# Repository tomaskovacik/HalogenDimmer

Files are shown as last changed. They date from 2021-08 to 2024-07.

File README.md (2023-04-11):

# HalogenDimmer
HW and SW for running halogen bulbs at 30% to act as daytime running lights.

# Overview
Module supports:
  - fade in at startup
  - fade out at shutdown
  - temporary disable with 3s delay (turn of DRL when turn signal is used, when using diodes more then one source of disable can used (low beams, turn signal... )
  - full on input for high beams, independent of microcontroler, used for light flasher and high beams
  - 30s turn off delay (comming home mode) - require permanent 12v supply and separete switched 12V connection to enable wire 
  
  # how-to connect module in headlight
  
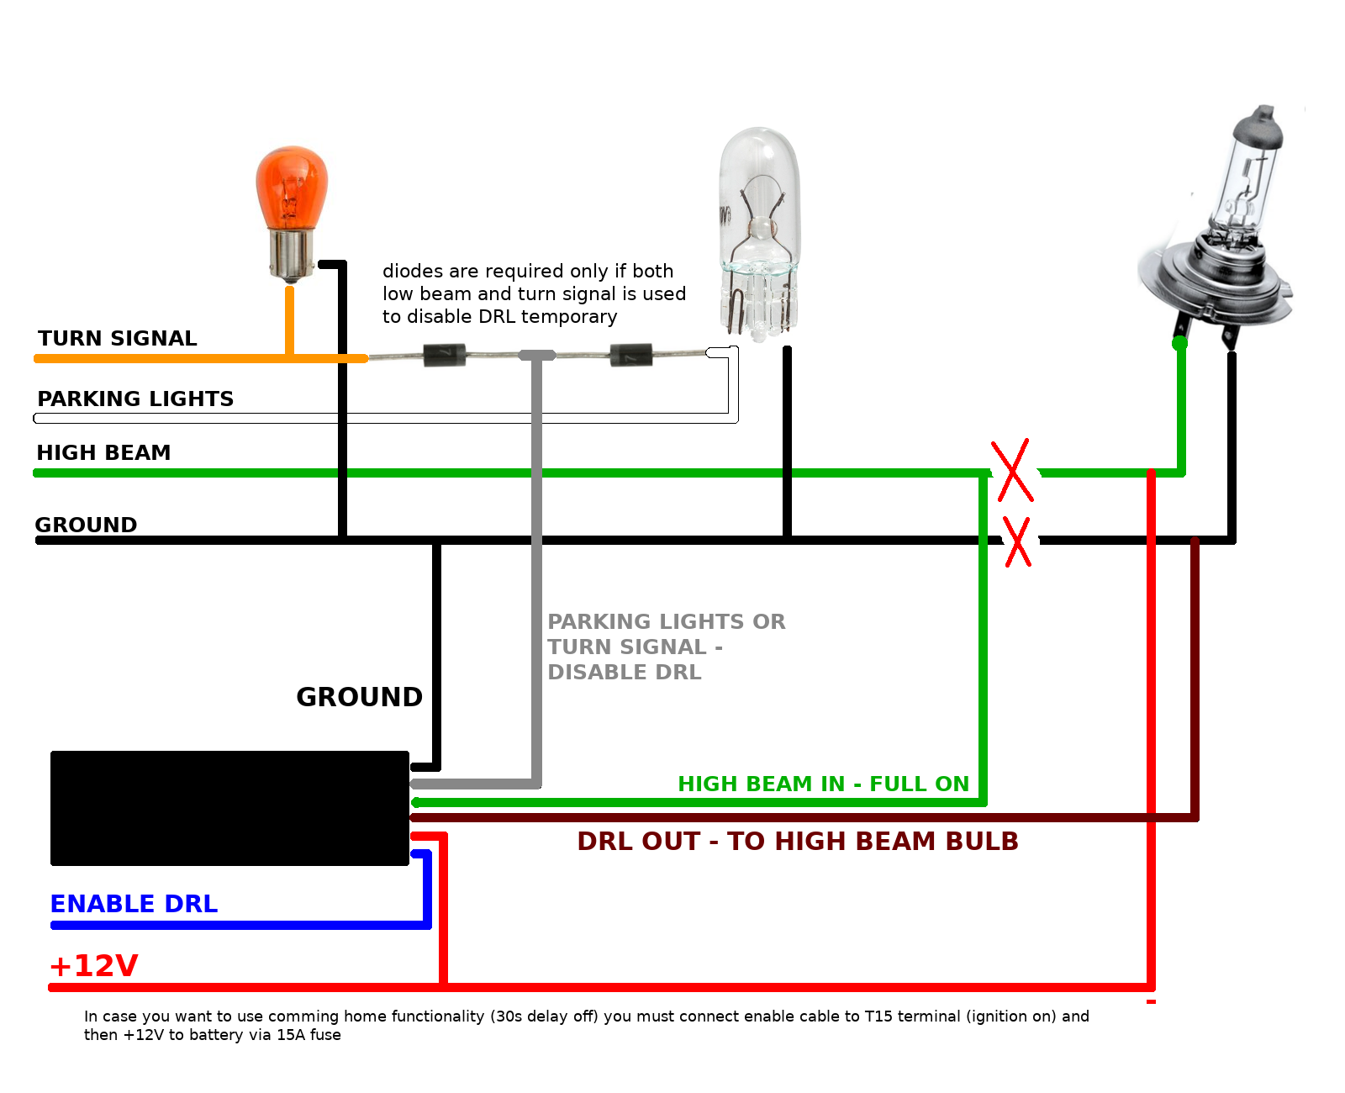
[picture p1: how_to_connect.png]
  
  
  # pinout
  
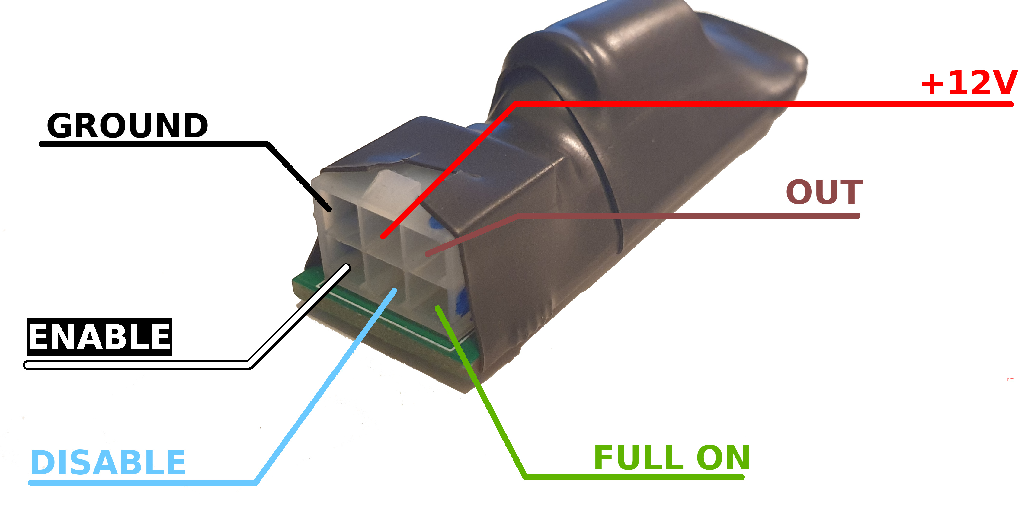
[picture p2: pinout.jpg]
  
  
  # video
  
  https://youtu.be/wNnqLfvapEo

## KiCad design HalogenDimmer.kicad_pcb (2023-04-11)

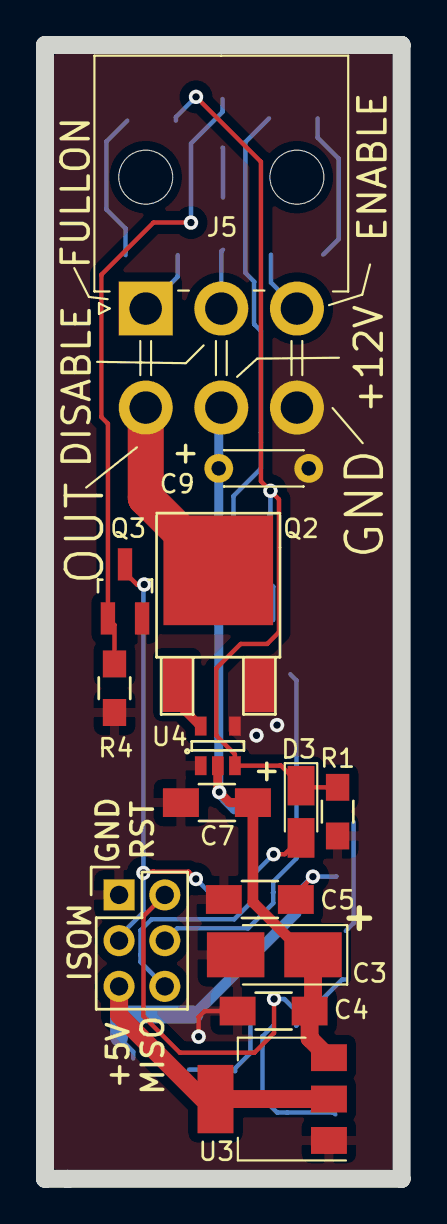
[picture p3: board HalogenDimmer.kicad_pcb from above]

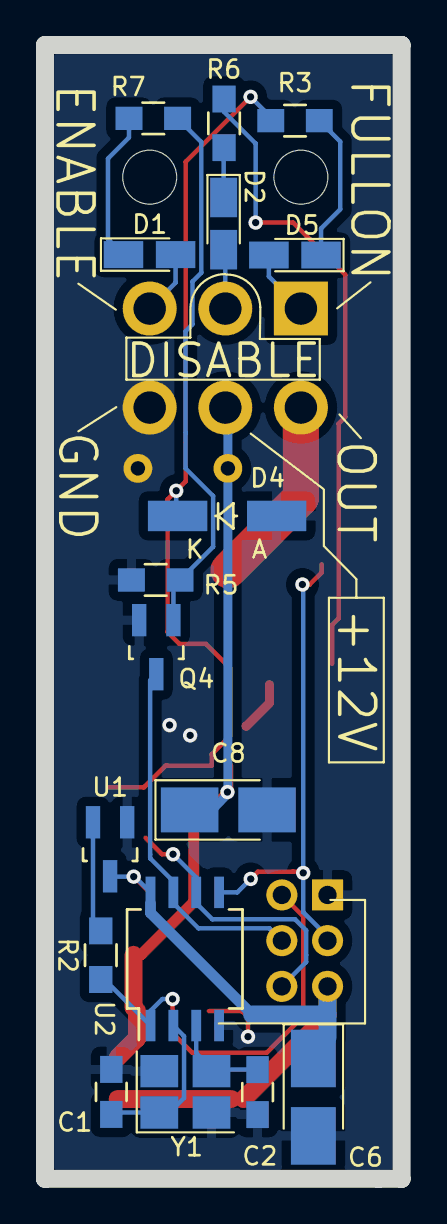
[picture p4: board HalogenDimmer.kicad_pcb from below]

Board: 2 copper layers, 19.8 x 63.0 mm, 31 parts (17 on the bottom side), 21 nets.

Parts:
C1, C2: 22p; C_0805_HandSoldering
C3: 22m/20V; CP_Tantalum_Case-B_EIA-3528-21_Hand
C4, C5, C7: 100n; C_1206_HandSoldering
C6: 47m/10V; CP_Tantalum_Case-B_EIA-3528-21_Hand
C8: 1m/10V; CP_Tantalum_Case-B_EIA-3528-21_Hand
C9: 1000m/16v; C_Disc_D4.3mm_W1.9mm_P5.00mm
D1, D2: NP; D_MicroMELF_Hadsoldering
D3, D5: 1n4148; D_MicroMELF_Hadsoldering
D4: 5V1; MiniMELF_Handsoldering
J1: SPI; Pin_Header_Straight_2x03
J5: INPUT_SIGNALS; Molex_MiniFit-JR-5569-06A2_2x03x4.20mm_Angled
Q2: IRL2905; TO-252-2Lead
Q3, Q4: BC817; SOT-23_Handsoldering
R1, R3, R4, R5: 1k; R_0805_HandSoldering
R2, R6, R7: 10k; R_0805_HandSoldering
U1: MAX809; SOT-23_Handsoldering
U2: ATtiny85-20SU; SO-8_5.3x6.2mm_Pitch1.27mm
U3: NCP1117LPST50T3G; SOT-223-3_TabPin2
U4: MCP1402; SOT-23-5
Y1: Crystal_GND24; Crystal_SMD_3225-4pin_3.2x2.5mm_HandSoldering

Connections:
+5V: C5.1, C6.1, J1.5, U1.3 (VCC), U2.8 (VCC), U3.2 (VO)
+12V: C3.1, C4.1, C7.1, C8.1, C9.1, J5.5, U3.3 (VI), U4.2 (Vdd)
/DISABLE: D2.2 (A), J5.2
/ENABLE: D1.2 (A), J5.3
/FULLON: D5.2 (A), J5.1
/MISO: D3.2 (A), J1.6, U2.6 (PB1)
/MOSI: J1.3, Q3.3 (C), U2.5 (AREF/PB0)
/OUT: J5.4, Q2.2 (D)
/PB2: J1.4, Q4.3 (C), U2.7 (PB2)
/RESET: J1.2, R2.1, U2.1 (~RESET~/PB5)
/XTAL1: C1.1, U2.2 (XTAL1/PB3), Y1.1
/XTAL2: C2.1, U2.3 (XTAL2/PB4), Y1.3
GND: C1.2, C2.2, C3.2, C4.2, C5.2, C6.2, C7.2, C8.2, C9.2, D4.2 (A), J1.1, J5.6, Q2.3 (S), Q3.2 (E), Q4.2 (E), R1.1, R4.2, R5.2, U1.1 (GND), U2.4 (GND), U3.1 (GND), U4.1 (GND), U4.4 (GND), Y1.2, Y1.4
unnamed: D1.1 (K), R7.2
unnamed: D2.1 (K), R6.2
unnamed: D3.1 (K), D4.1 (K), R1.2, R3.1, U4.3 (IN)
unnamed: D5.1 (K), R3.2
unnamed: Q2.1 (G), U4.5 (OUT)
unnamed: Q3.1 (B), R4.1, R6.1
unnamed: Q4.1 (B), R5.1, R7.1
unnamed: R2.2, U1.2 (RESET)

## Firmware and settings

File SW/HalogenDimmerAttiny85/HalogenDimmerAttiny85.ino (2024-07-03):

// (c) kovo
//hallogen dimmer

/*
 * 3.7.2024 kovo: typos, cleanup commented out code 
 */

//timer1 @ 64Mhz
#include <avr/sleep.h>    // Sleep Modes
#include <avr/power.h>    // Power management

#define DELAY 50 // delay used in fade in, used to start DRL
#define DUTY 30 // duty cycle for DRL
#define OUT_PIN 1   //PB1 - output for PWM signal 
#define ONOFF_PIN 2    //PB2 - detecting if ON/OFFF state + wakeup from sleep - must be PB2 because INT0
#define DISABLE_PIN 0   //PB0 - detecting turnsignal, lowbeam etc to disable PWM high beam output
#define TURNSIGNAL_DELAY 5000 //safe delay to enable back DRL's if not turnsignal is present (or lowbeams...)
#define COMMING_HOME_DELAY 30000

enum state {
  OFF, // everything is off
  ON,// DRL ON
  SLEEP, //LOWPOWER MODE
  DISABLE, //LOW BEAMS ON,TURNSIGNAL ON, DRL OFF, NO SLEEP
  COMMING_HOME //30s delay before sleep
};


volatile uint8_t status = OFF;
volatile long disable_start_time;
volatile long offdelay_time;
volatile uint8_t set_duty = 0;

void go2sleep ()
{
  set_duty=0;
  analogWrite(OUT_PIN, set_duty);
  PCMSK  |= bit (PCINT2);  // want pin D4 / pin 3
  GIFR   |= bit (PCIF);    // clear any outstanding interrupts
  GIMSK  |= bit (PCIE);    // enable pin change interrupts
  set_sleep_mode(SLEEP_MODE_PWR_DOWN);
  ADCSRA = 0;            // turn off ADC
  power_all_disable();  // power off ADC, Timer 0 and 1, serial interface
  sleep_enable();
  sleep_cpu();
  sleep_disable();
  power_all_enable();    // power everything back on
  GIMSK  &= ~ (1 << PCIE); // enable pin change interrupts
  status = OFF;
}  // end of goToSleep

void DRL_ON() {
  for (set_duty = 0; set_duty < DUTY; set_duty++) {
    //while we are spinning on DRL, DISABLE pin is set (we start LOW beams of exmaple) 
    // so we cut turning on DRL 
    //and imidietly jump to turning them off = fade out
    if (!digitalRead(DISABLE_PIN))
    {
      delay(50);//debounce
      if (!digitalRead(DISABLE_PIN)) {
        disable_start_time = millis();
        status = DISABLE;
        return;
      }
    }
    analogWrite(OUT_PIN, set_duty);
    delay(DELAY); //DELAY=50ms, duty 30 => rump up is 1500ms aka 1.5s
  }
  //all good, we DRL is ON
  status = ON;
}

void DRL_OFF() {
  for (set_duty; set_duty > 0; set_duty--) {
    //do not checking for pin status, this rutine is used in more then one places
    //pin DISABLE change is handled in main loop
    analogWrite(OUT_PIN, set_duty);
    delay(DELAY); //DELAY=50ms, duty 30 => rump up is 1500ms aka 1.5s
  }
  //analogWrite(OUT_PIN, 0);//should not be needed....
  status = OFF;
}

void setup() {
  //  uncoment for 32kHz ouput
  //  TCCR1 &=~(1<<CS13);
  //  TCCR1 &=~(1<<CS12);
  //  TCCR1 &=~(1<<CS11);
  //  TCCR1 |=(1<<CS10);
  pinMode(DISABLE_PIN, INPUT_PULLUP);
  pinMode(ONOFF_PIN, INPUT_PULLUP);
  digitalWrite(OUT_PIN, LOW);
  pinMode(OUT_PIN, OUTPUT);
  digitalWrite(OUT_PIN, LOW);
}

void loop() {
  switch (status) {
    case OFF:
      //wakeded up, and goes straight to low beams = disable pin is low
      if (!digitalRead(ONOFF_PIN)) //HW inverted, using transistor 
        //we start drl and disable it in next run in main loop
        DRL_ON(); 
      else
        go2sleep();
      break;
    case ON:
      if (!digitalRead(DISABLE_PIN)) {
        delay(50);//debounce
        if (!digitalRead(DISABLE_PIN)) {
          status = DISABLE;
        }
      }
      if (digitalRead(ONOFF_PIN)) {
        delay(50);
        if (digitalRead(ONOFF_PIN)) {
          offdelay_time = millis() + 30000;
          while ((millis() < offdelay_time) && digitalRead(ONOFF_PIN)); //wait for 30s
          go2sleep();
        }
      }
      break;
    case SLEEP:
      //this should not happened, but in case, sleep:
      analogWrite(OUT_PIN, 0);
      go2sleep();
      break;
    case DISABLE:
      disable_start_time = millis();
      DRL_OFF();
      //loop for 3seconds if DISABLE pin is not set
      //otherwise loop forever
      while ((millis() - disable_start_time) < 3000) {
        if (!digitalRead(DISABLE_PIN)) {
          delay(50);//debounce
          if (!digitalRead(DISABLE_PIN)) {
            disable_start_time = millis();
          }
        }
      }
      break;

  }
}
